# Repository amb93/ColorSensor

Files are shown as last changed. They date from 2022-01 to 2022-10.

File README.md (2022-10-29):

# Color sensor
A compact device that helps the blind and color blind to differentiate between colors. The devices shows the color on the top screen and has an AUX plug for voice. Fully rechargable, lasting over 10 hours.

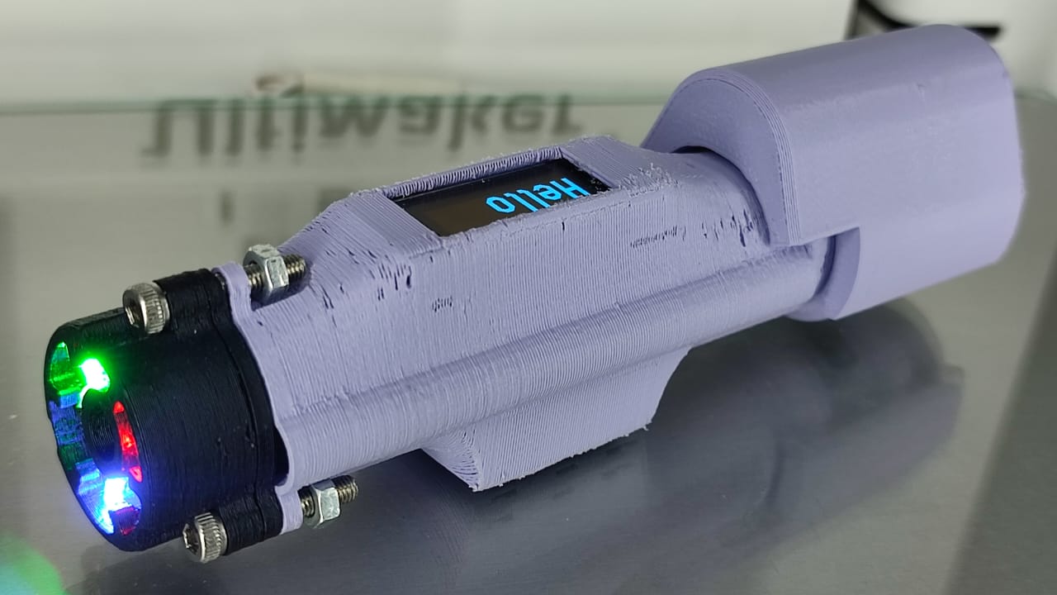
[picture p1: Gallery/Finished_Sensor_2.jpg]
Final


# Work progress
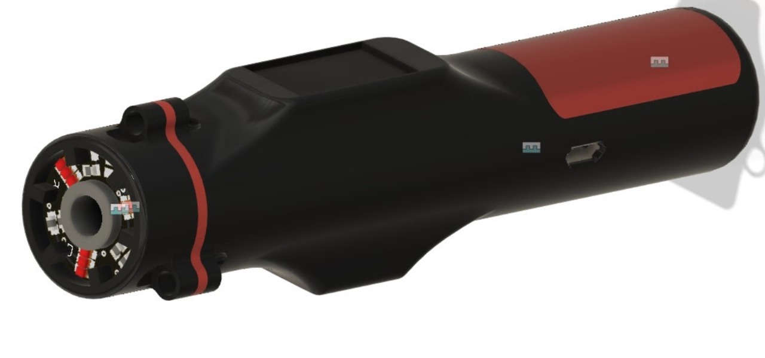
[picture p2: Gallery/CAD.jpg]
Design

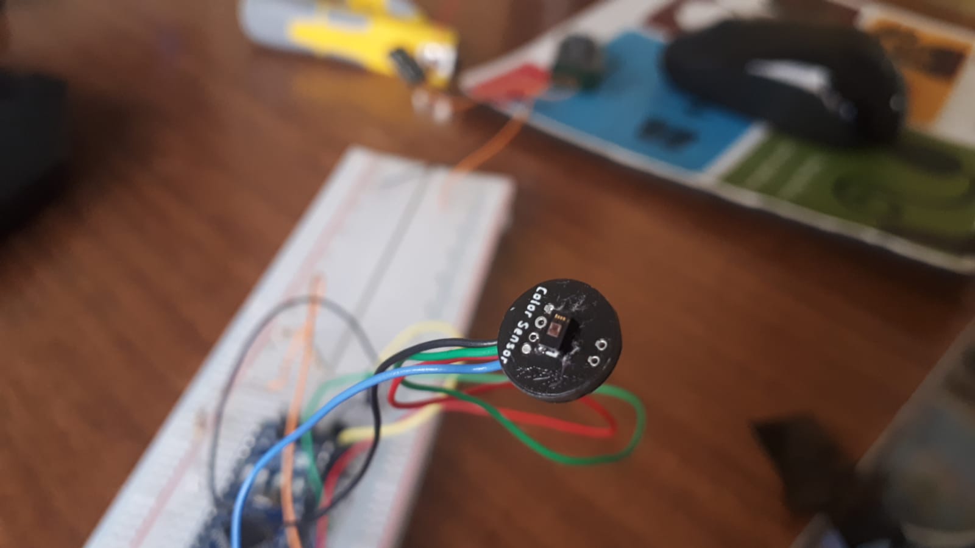
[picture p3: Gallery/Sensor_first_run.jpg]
Sensor_board

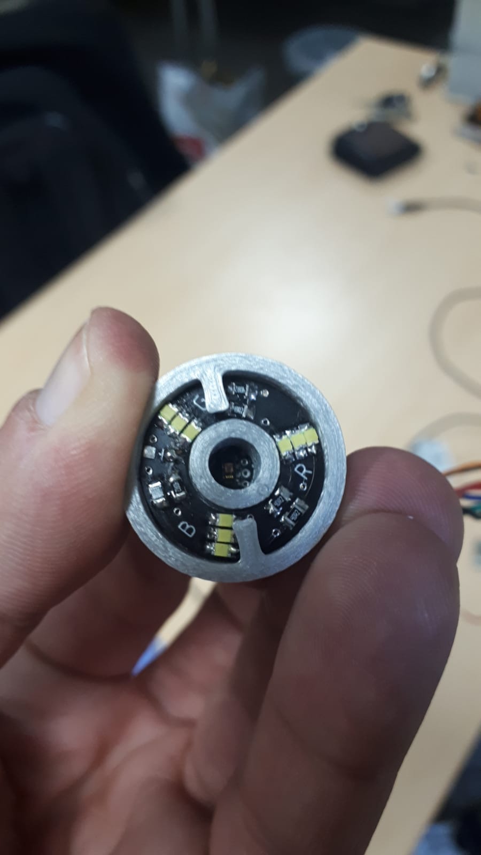
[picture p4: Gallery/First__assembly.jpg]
assembly

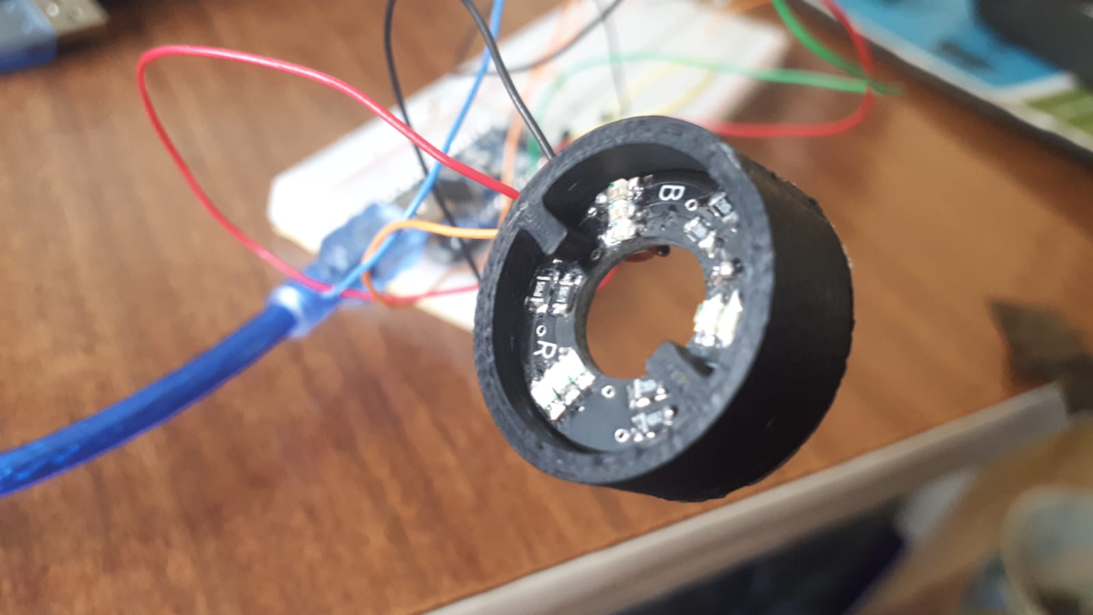
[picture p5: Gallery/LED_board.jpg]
LED_Board

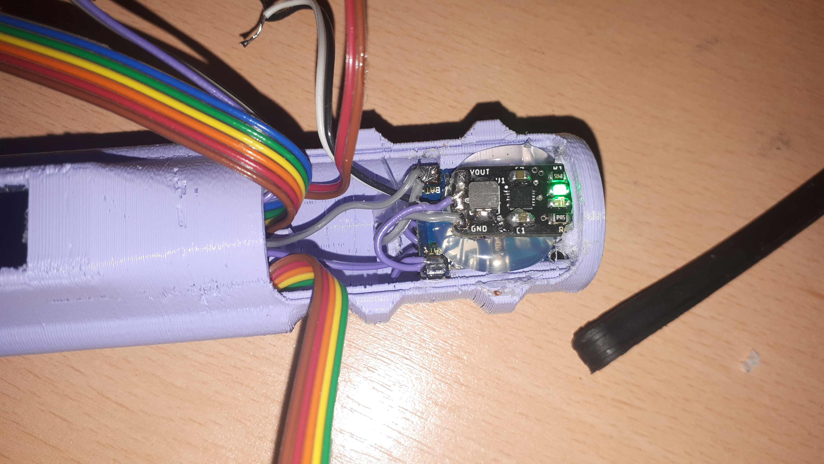
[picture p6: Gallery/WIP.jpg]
WIP

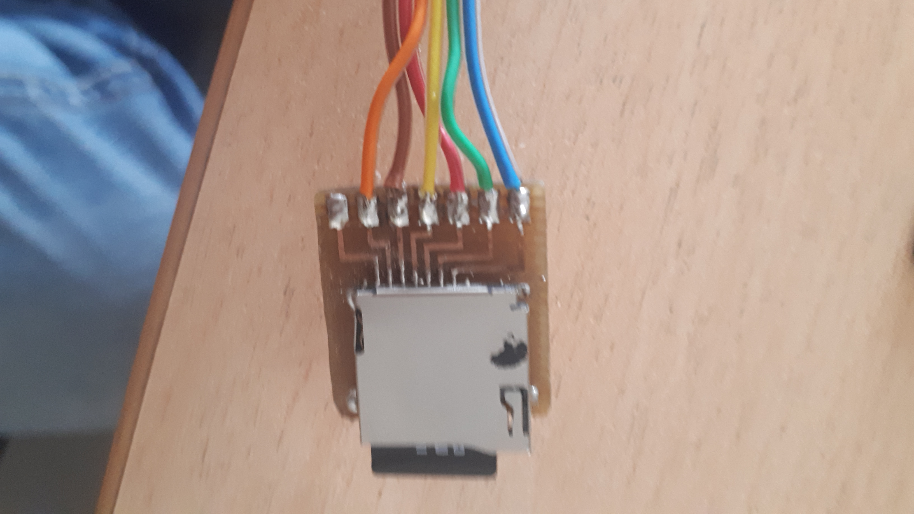
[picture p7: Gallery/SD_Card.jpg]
SD_card

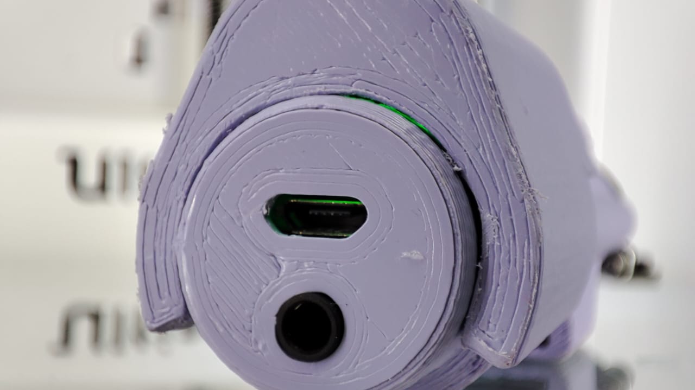
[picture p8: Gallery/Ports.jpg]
ports

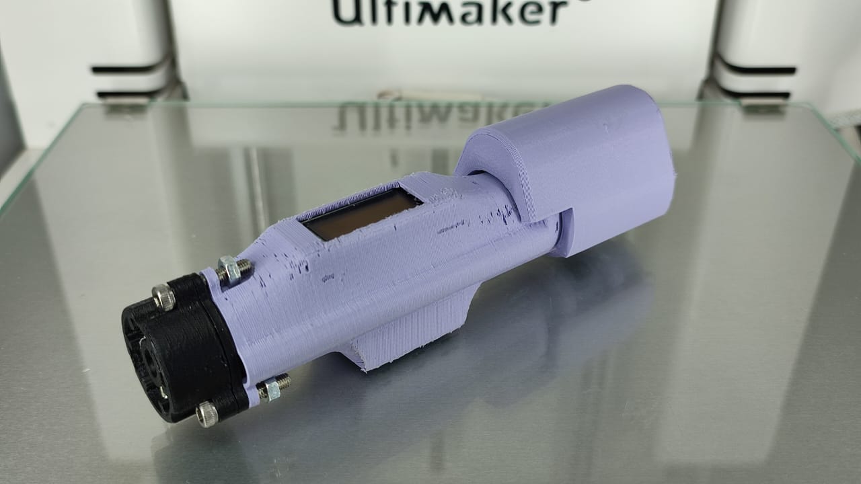
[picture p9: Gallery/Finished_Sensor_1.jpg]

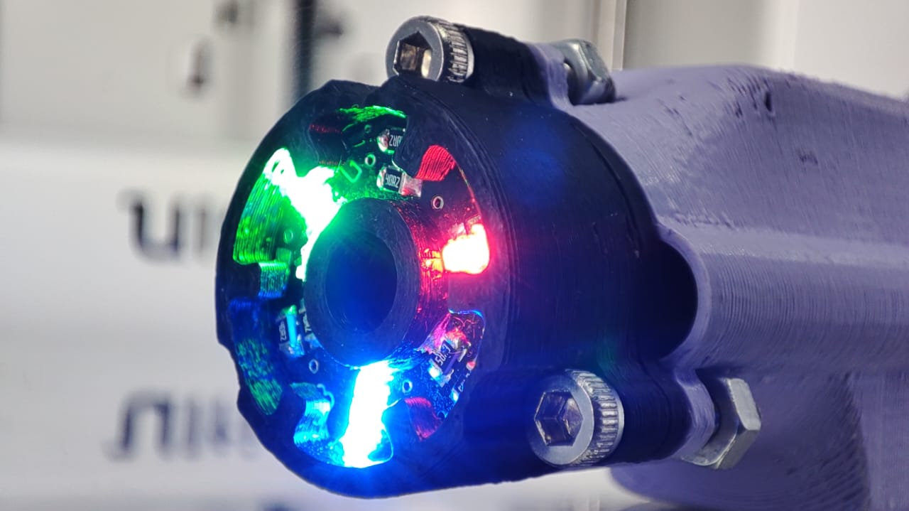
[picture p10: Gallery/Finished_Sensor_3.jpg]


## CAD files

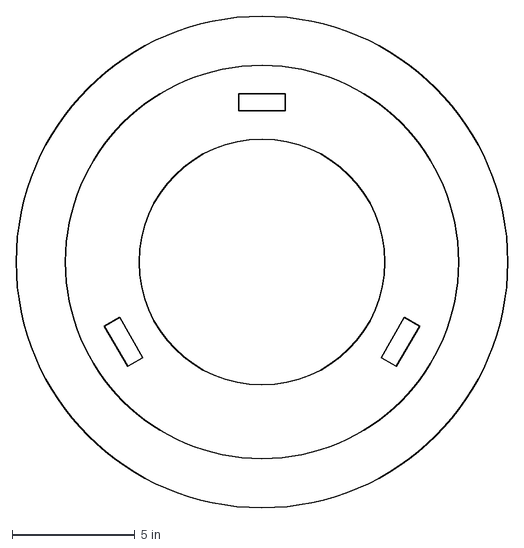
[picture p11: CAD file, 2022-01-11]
PCB Design/Border_Sens.dxf
20.0 x 20.0 in

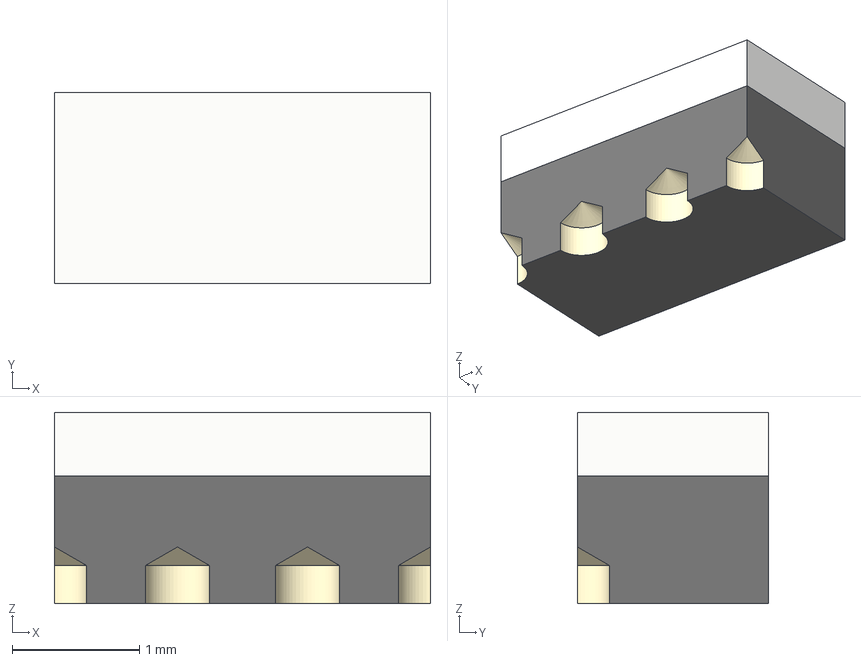
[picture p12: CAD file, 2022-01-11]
PCB Design/VEML3328SL.step
2.95 x 1.50 x 1.50 mm

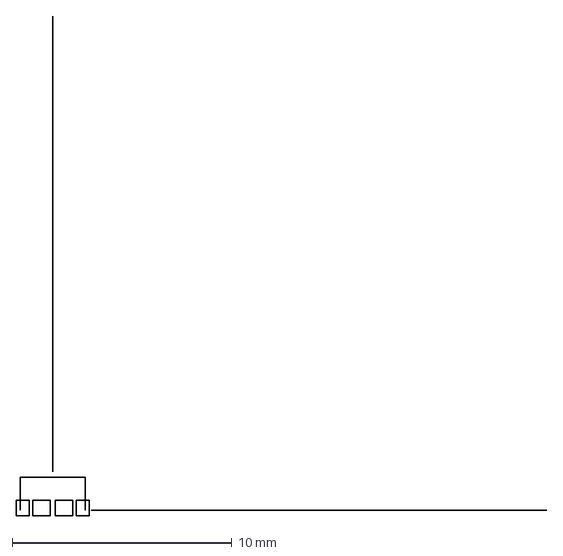
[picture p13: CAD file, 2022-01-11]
PCB Design/VEML3328SL FOOTPRINT.dxf
24.2 x 22.8 mm

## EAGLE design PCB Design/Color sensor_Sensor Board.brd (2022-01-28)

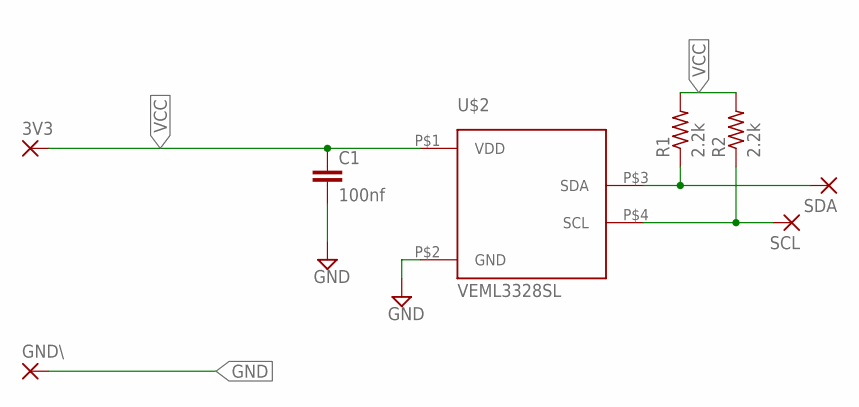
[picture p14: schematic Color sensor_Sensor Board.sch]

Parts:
3V3: SMD2; SMD1,27-2,54
C1: 100nf; C0805
GND\: SMD2; SMD1,27-2,54
R1, R2: 2.2k; R0805
SCL: SMD2; SMD1,27-2,54
SDA: SMD2; SMD1,27-2,54
U$2: VEML3328SL; OPLGA4SV

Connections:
GND: C1.2, GND\.1, U$2.P$2 (GND)
unnamed: R1.1, SDA.1, U$2.P$3 (SDA)
unnamed: R2.1, SCL.1, U$2.P$4 (SCL)
VCC: 3V3.1, C1.1, R1.2, R2.2, U$2.P$1 (VDD)

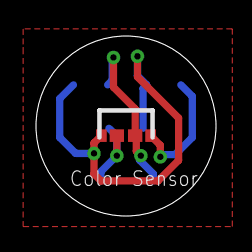
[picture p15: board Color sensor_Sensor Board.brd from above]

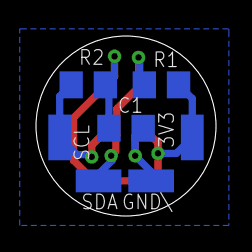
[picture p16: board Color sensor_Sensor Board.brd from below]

Board: 2 copper layers, 10.0 x 10.0 mm, 8 parts (7 on the bottom side), 4 nets.

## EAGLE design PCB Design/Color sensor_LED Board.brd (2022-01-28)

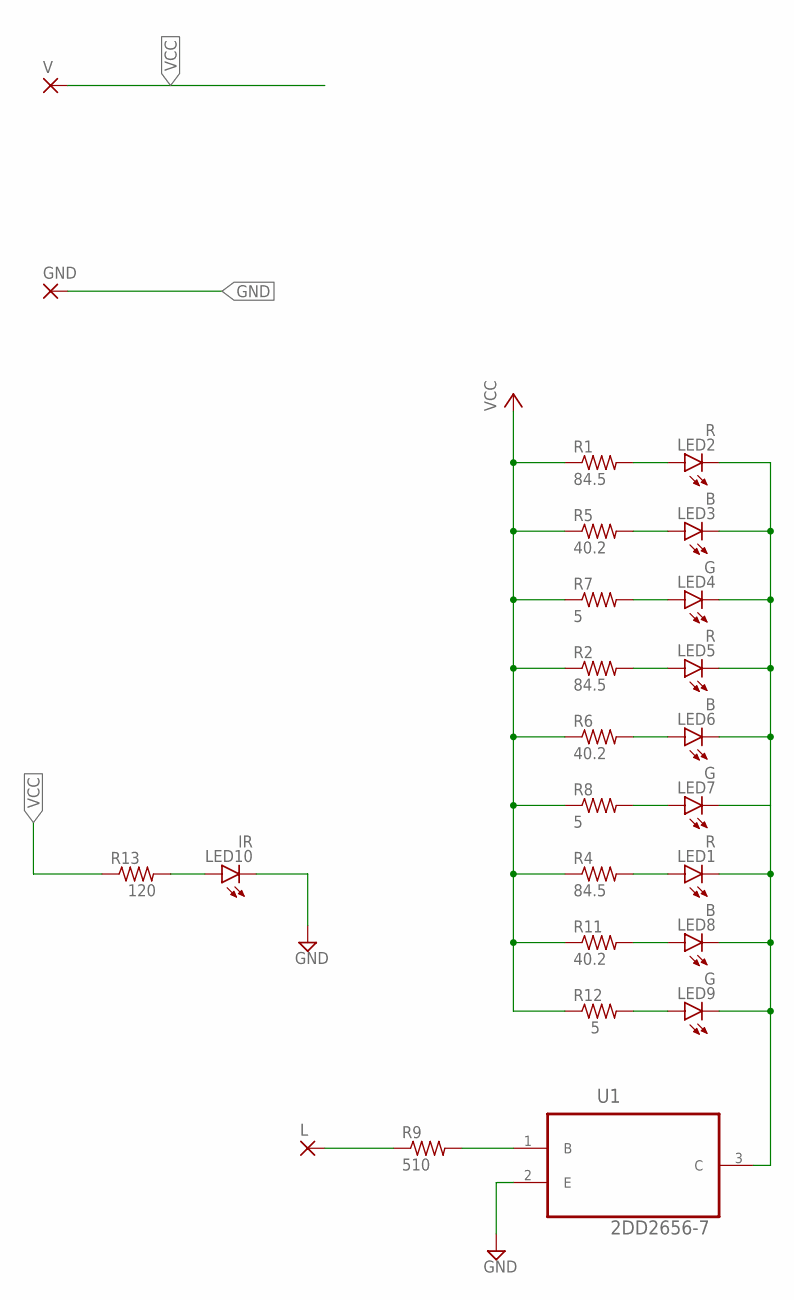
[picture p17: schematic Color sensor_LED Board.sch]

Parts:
GND: SMD2; SMD1,27-2,54
L: SMD2; SMD1,27-2,54
LED1, LED2, LED5: R; CHIPLED_0805
LED3, LED6, LED8: B; CHIPLED_0805
LED4, LED7, LED9: G; CHIPLED_0805
LED10: IR; CHIPLED_0805
R1, R2, R4: 84.5; R0805
R5, R6, R11: 40.2; R0805
R7, R8, R12: 5; R0805
R9: 510; R0805
R13: 120; R0805
U1: 2DD2656-7; SOT65P210X110-3N
V: SMD2; SMD1,27-2,54

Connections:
GND: GND.1, LED10.C, U1.2 (E)
unnamed: R9.2, U1.1 (B)
unnamed: L.1, R9.1
unnamed: LED2.A, R1.2
unnamed: LED3.A, R5.2
unnamed: LED4.A, R7.2
unnamed: LED5.A, R2.2
unnamed: LED6.A, R6.2
unnamed: LED7.A, R8.2
unnamed: LED1.A, R4.2
unnamed: LED8.A, R11.2
unnamed: LED9.A, R12.2
unnamed: LED1.C, LED2.C, LED3.C, LED4.C, LED5.C, LED6.C, LED7.C, LED8.C, LED9.C, U1.3 (C)
unnamed: LED10.A, R13.2
VCC: R1.1, R2.1, R4.1, R5.1, R6.1, R7.1, R8.1, R11.1, R12.1, R13.1, V.1

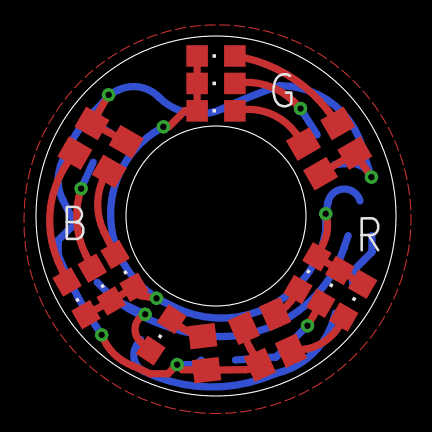
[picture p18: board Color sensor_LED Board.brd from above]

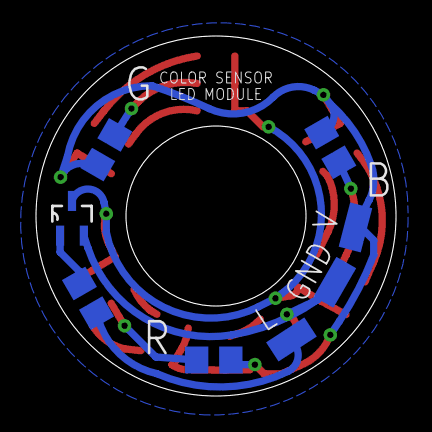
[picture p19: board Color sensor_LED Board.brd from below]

Board: 2 copper layers, 20.0 x 20.0 mm, 25 parts (8 on the bottom side), 15 nets.

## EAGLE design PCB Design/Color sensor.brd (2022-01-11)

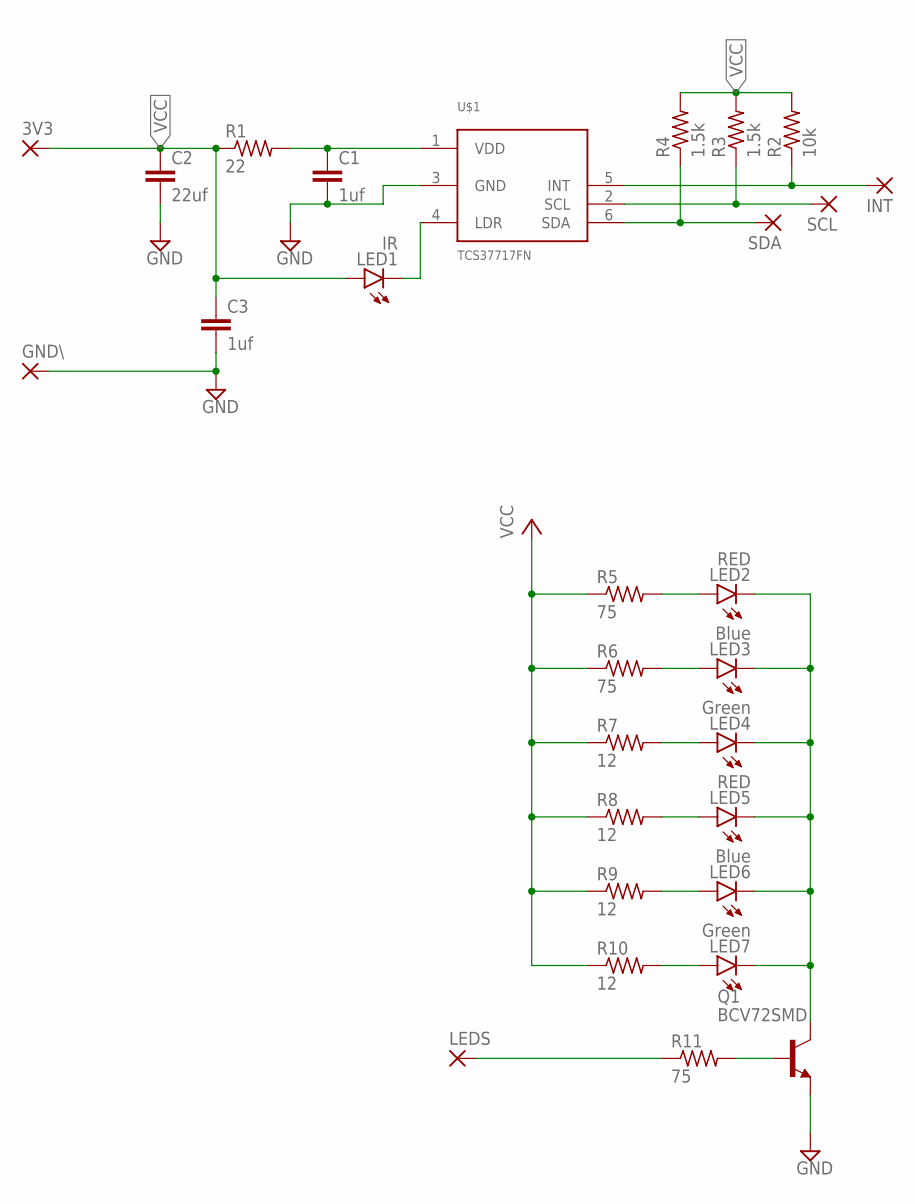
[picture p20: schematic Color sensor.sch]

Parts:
3V3: SMD2; SMD1,27-2,54
C1, C3: 1uf; C0402
C2: 22uf; C0402
GND\: SMD2; SMD1,27-2,54
INT: SMD2; SMD1,27-2,54
LED1: IR; CHIPLED_0805
LED2, LED5: RED; CHIPLED_0805
LED3, LED6: Blue; CHIPLED_0805
LED4, LED7: Green; CHIPLED_0805
LEDS: SMD2; SMD1,27-2,54
Q1: BCV72SMD; SOT23-BEC
R1: 22; R0402
R2: 10k; R0402
R3, R4: 1.5k; R0402
R5, R6, R11: 75; R0402
R7, R8, R9, R10: 12; R0402
SCL: SMD2; SMD1,27-2,54
SDA: SMD2; SMD1,27-2,54
U$1: TCS37717FN; SON65P200X240X70-6N

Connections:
GND: C1.2, C2.2, C3.2, GND\.1, Q1.E, U$1.3 (GND)
INT: INT.1, R2.1, U$1.5 (INT)
LDR: LED1.C, U$1.4 (LDR)
unnamed: C1.1, R1.2, U$1.1 (VDD)
unnamed: Q1.B, R11.2
unnamed: LED2.C, LED3.C, LED4.C, LED5.C, LED6.C, LED7.C, Q1.C
unnamed: LEDS.1, R11.1
unnamed: LED2.A, R5.2
unnamed: LED3.A, R6.2
unnamed: LED4.A, R7.2
unnamed: LED5.A, R8.2
unnamed: LED6.A, R9.2
unnamed: LED7.A, R10.2
SCL: R3.1, SCL.1, U$1.2 (SCL)
SDA: R4.1, SDA.1, U$1.6 (SDA)
VCC: 3V3.1, C2.1, C3.1, LED1.A, R1.1, R2.2, R3.2, R4.2, R5.1, R6.1, R7.1, R8.1, R9.1, R10.1

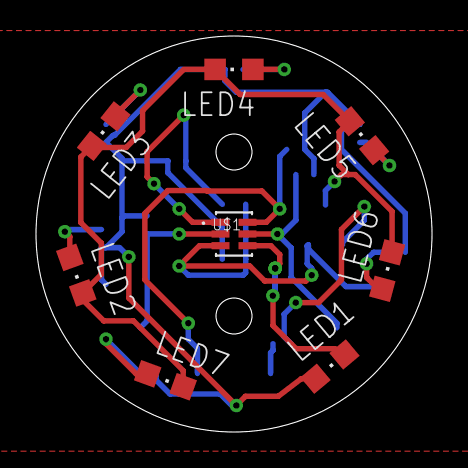
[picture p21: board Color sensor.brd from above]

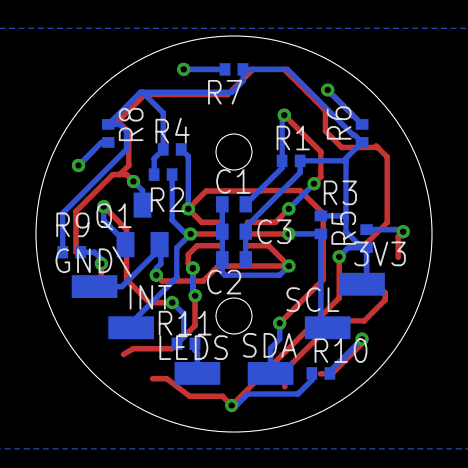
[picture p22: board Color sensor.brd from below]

Board: 2 copper layers, 22.0 x 22.0 mm, 29 parts (21 on the bottom side), 16 nets.

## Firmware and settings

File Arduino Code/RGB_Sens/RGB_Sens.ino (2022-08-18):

/*
 MIT License

Copyright (c) 2022 Developium

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
 * Arduino library for the Vishay VEML3328 and VEML3328sl sensors
 * funtions:
 * bool RGBCIR.begin(void); look for the sensor in the I2C bus, return 0 if sensor not found
 * void RGBCIR.Enable(void); Turn on the sensor'channels (off by default)
 * void Disable(void); Turn off the sensor
 * uint16_t getRed(void); get the red channel's reading from 0-65535
 * uint16_t getGreen(void); get the green channel's reading from 0-65535
 * uint16_t getBlue(void); get the blue channel's reading from 0-65535
 * uint16_t getClear(void); get the clear channel's reading from 0-65535
 * uint16_t getIR(void); get the IR channel's reading from 0-65535
 * void setSensitivity(bool); toggle between two sensitivity modes; 0 for low sensitivity and 1 for high
 * void setGain(float); set the gain of the sensor, choose between 0.5, 1, 2, 4 (1 default)
 * void setDG(uint8_t); set the digital gain of the sensor, choose between 1, 2, 4 (1 default)
 * void setIntegrationTime(uint16_t); set the integration time of the sensor, choose between IT_50MS, IT_100MS, IT_200MS, IT_400MS (in milliseconds)
 * uint16_t getCommandReg(void); Read the value of the command register
 * 
 * refer to the datasheet: https://www.vishay.com/docs/80012/veml3328sl.pdf
 * 
 * By: amb93
 */

#include "Wire.h"
#include "VEML3328.h"
#include <U8g2lib.h>
#include <SD.h>                      // need to include the SD library
#define SD_ChipSelectPin 4  //using digital pin 4 on arduino nano 328, can use other pins
#include <TMRpcm.h>           //  also need to include this library...
#include <SPI.h>

#define white "white.wav"
#define black "black.wav"
#define red "red.wav"
#define orange "orange.wav"
#define yellow "yellow.wav"
#define green "green.wav"
#define cyan "cyan.wav"
#define blue "blue.wav"
#define purple "purple.wav"


TMRpcm tmrpcm;   // create an object for use in this sketch



VEML3328 RGBCIR;

float R_cal = 1.0;
float G_cal = 1.0;
float B_cal = 1.0;

void setup() {

  Wire.begin();
  tmrpcm.speakerPin = 9; //5,6,11 or 46 on Mega, 9 on Uno, Nano, etc 

  
  //Serial.println("Vishay VEML3328 RGBCIR color sensor");
  RGBCIR.Enable(); 
  RGBCIR.setGain(1);
  RGBCIR.setSensitivity(high_sens);
  RGBCIR.setDG(4);
  RGBCIR.setIntegrationTime(IT_400MS);

  SD.begin(SD_ChipSelectPin);

 OLED_Print("Hello");
 tmrpcm.play("welcome.wav");
 
 delay(5000);

R_cal = RGBCIR.getRed();
G_cal = RGBCIR.getGreen();
B_cal = RGBCIR.getBlue();

}

void loop() {
  
  // Use the arduino's serial plotter

  
 float Red = RGBCIR.getRed()/R_cal;
 float Green = RGBCIR.getGreen()/G_cal;
 float Blue = RGBCIR.getBlue()/B_cal;
 
 float Hue = RGB2H(Red,Green,Blue);
 float Val = RGB2V(Red,Green,Blue);
 float Sat = RGB2S(Red,Green,Blue);

  String color = colorDetect(Hue,255*Sat,255*Val);
  OLED_Print(color);
  String filename = color + ".wav";
  tmrpcm.play(filename.c_str());
  delay(500);
}

float RGB2H(float r,float g,float b)
{
  float Cmax = max(max(r,g),b);
  float Cmin = min(min(r,g),b);
  float diff = Cmax - Cmin;
  float h;
  if (diff == 0)
  {
    return 0;
  }
  else if (Cmax == r)
  {
    h = (g - b) / diff ;
     
  }
  else if (Cmax == g)
  {
     h = 2.0 + (b - r) / diff ;
     
  }

    else if (Cmax == b)
  {
     h = 4.0 + (r - g) / diff ;
  }
  h *= 60.0; 
  if (h<0.0) h +=360.0;
  
  return h;
}

float RGB2S(float r,float g,float b)
{
  float Cmax = max(max(r,g),b);
  float Cmin = min(min(r,g),b);
  float diff = Cmax - Cmin;
  float S;
  float V;
  V = Cmax;
  S =   (Cmax-Cmin)/Cmax;
  if (V==0) S=0;
  
  return S;
}

float RGB2V(float r,float g,float b)
{
  float Cmax = max(max(r,g),b);
  float V;
  V = Cmax;
  return V;
}

String colorDetect(float H,float S,float V)
{
  if (S<20)
  {
    return "white";
  }
  else if (V<20)
  {
    return "black";
  }
  else if (H<=40)
  {
    return "red";
  }
  else if (H<=65)
  {
    return "yellow";
  }
  else if (H<=160)
  {
    return "green";
  }
  else if (H<=210)
  {
    return "cyan";
  }
  else if (H<=270)
  {
    return "blue";
  }
  else if (H>270)
  {
    return "purple";
  }

}

void OLED_Print(String out)
{
  U8G2_SSD1306_128X32_UNIVISION_F_HW_I2C u8g2(U8G2_R0); 
  u8g2.begin();
  
  u8g2.clearBuffer();          // clear the internal memory
  u8g2.setFont(u8g2_font_logisoso28_tr);  // choose a suitable font at https://github.com/olikraus/u8g2/wiki/fntlistall
  u8g2.drawStr(8,29,out.c_str());  // write something to the internal memory
  u8g2.sendBuffer();         // transfer internal memory to the display
}

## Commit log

2022-01-11 Uploaded PCB design
    [Border_Sens.dxf, Color sensor.brd, Color sensor.sch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]
2022-01-11 Arduino libary added as a submodule
2022-01-15 corrected unconnected traces and IR LED problem
    [Color sensor_LED Board.brd, Color sensor_LED Board.sch]
2022-01-28 added arduino code
    [Color sensor_LED Board.brd, Color sensor_Sensor Board.brd]
